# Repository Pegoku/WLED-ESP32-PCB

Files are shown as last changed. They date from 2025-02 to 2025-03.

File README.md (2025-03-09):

# WLED-PCB

This project is a WLED Controller designed using KiCad. The WLED-PCB is controlled using an ESP32 and can be powered via the Screw Terminals. It is capable of driving multiple RGB Strips and Neopixels. It also has a Fuse Holder per channel to protect the circuit from overcurrent.

## Schematic
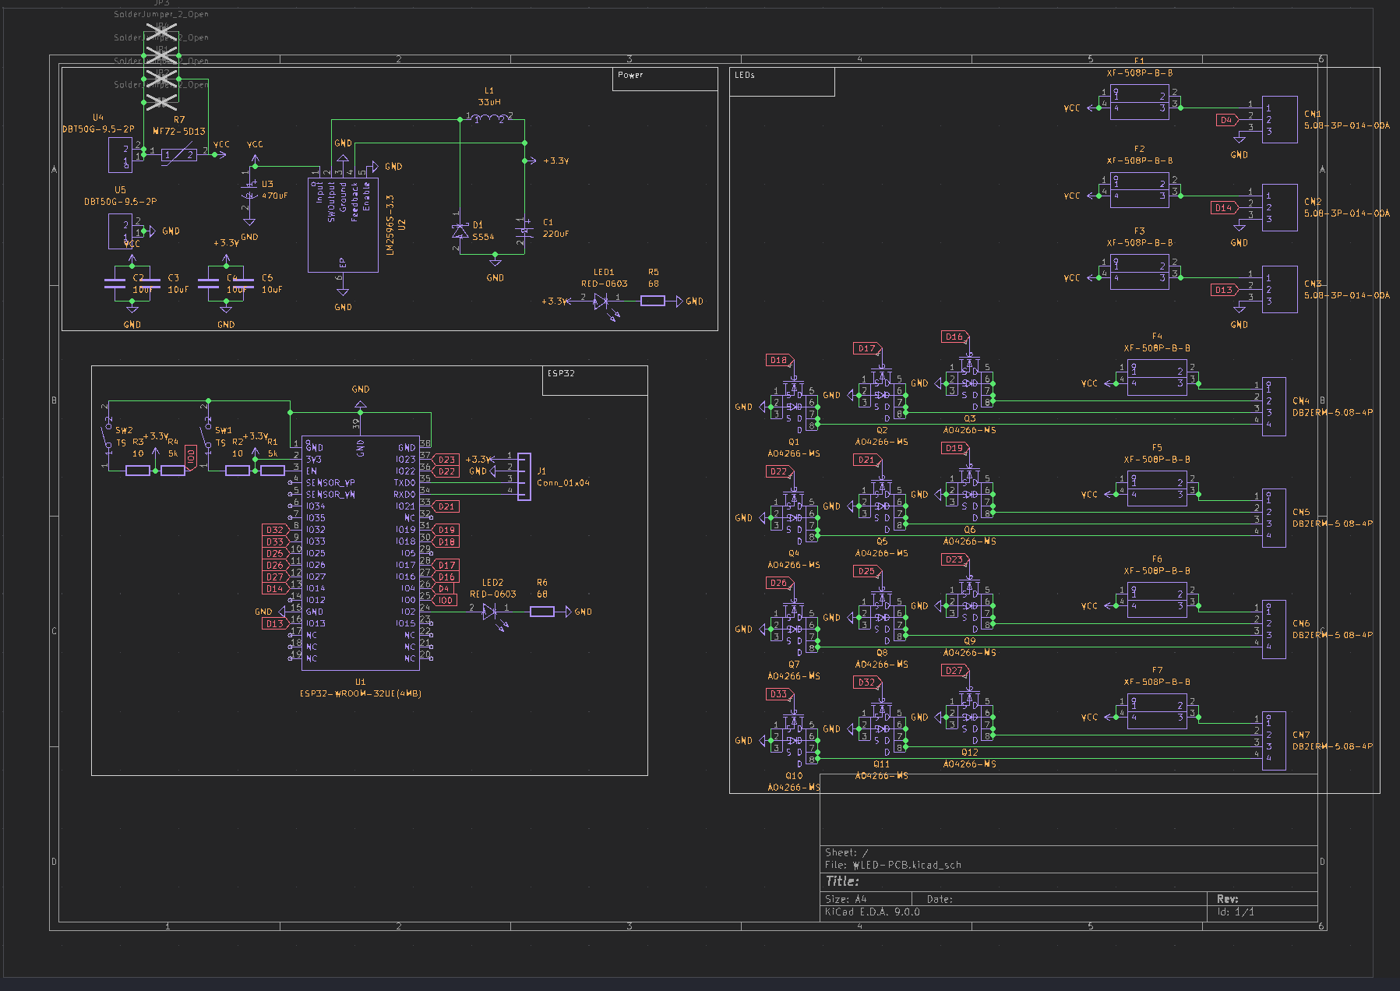
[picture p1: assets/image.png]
Schematic


## PCB Layout
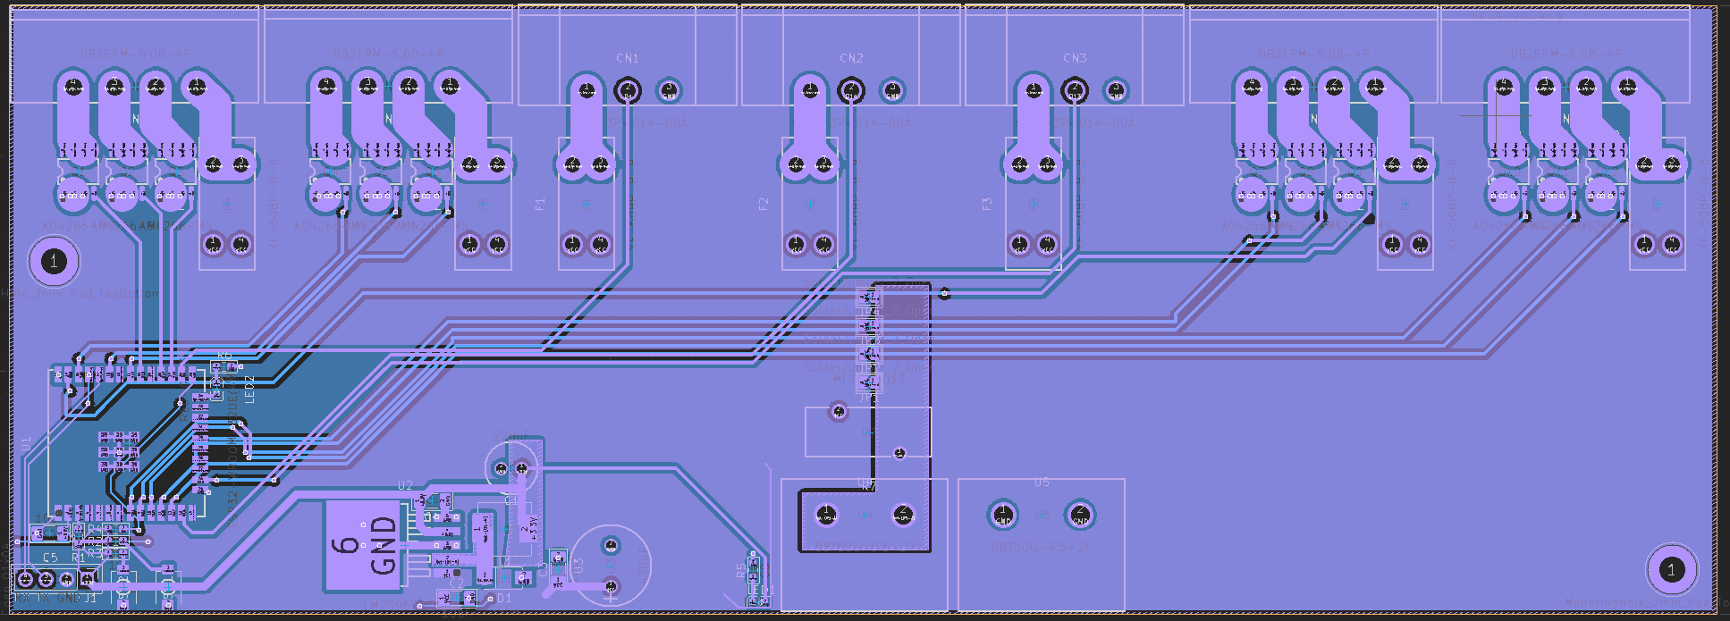
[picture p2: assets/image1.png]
PCB Layout


## 3D View
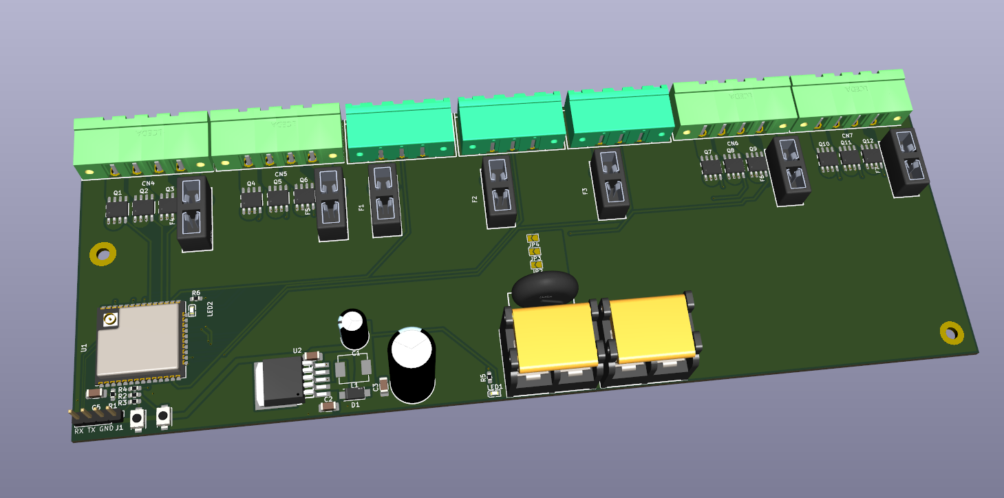
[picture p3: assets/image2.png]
3D View


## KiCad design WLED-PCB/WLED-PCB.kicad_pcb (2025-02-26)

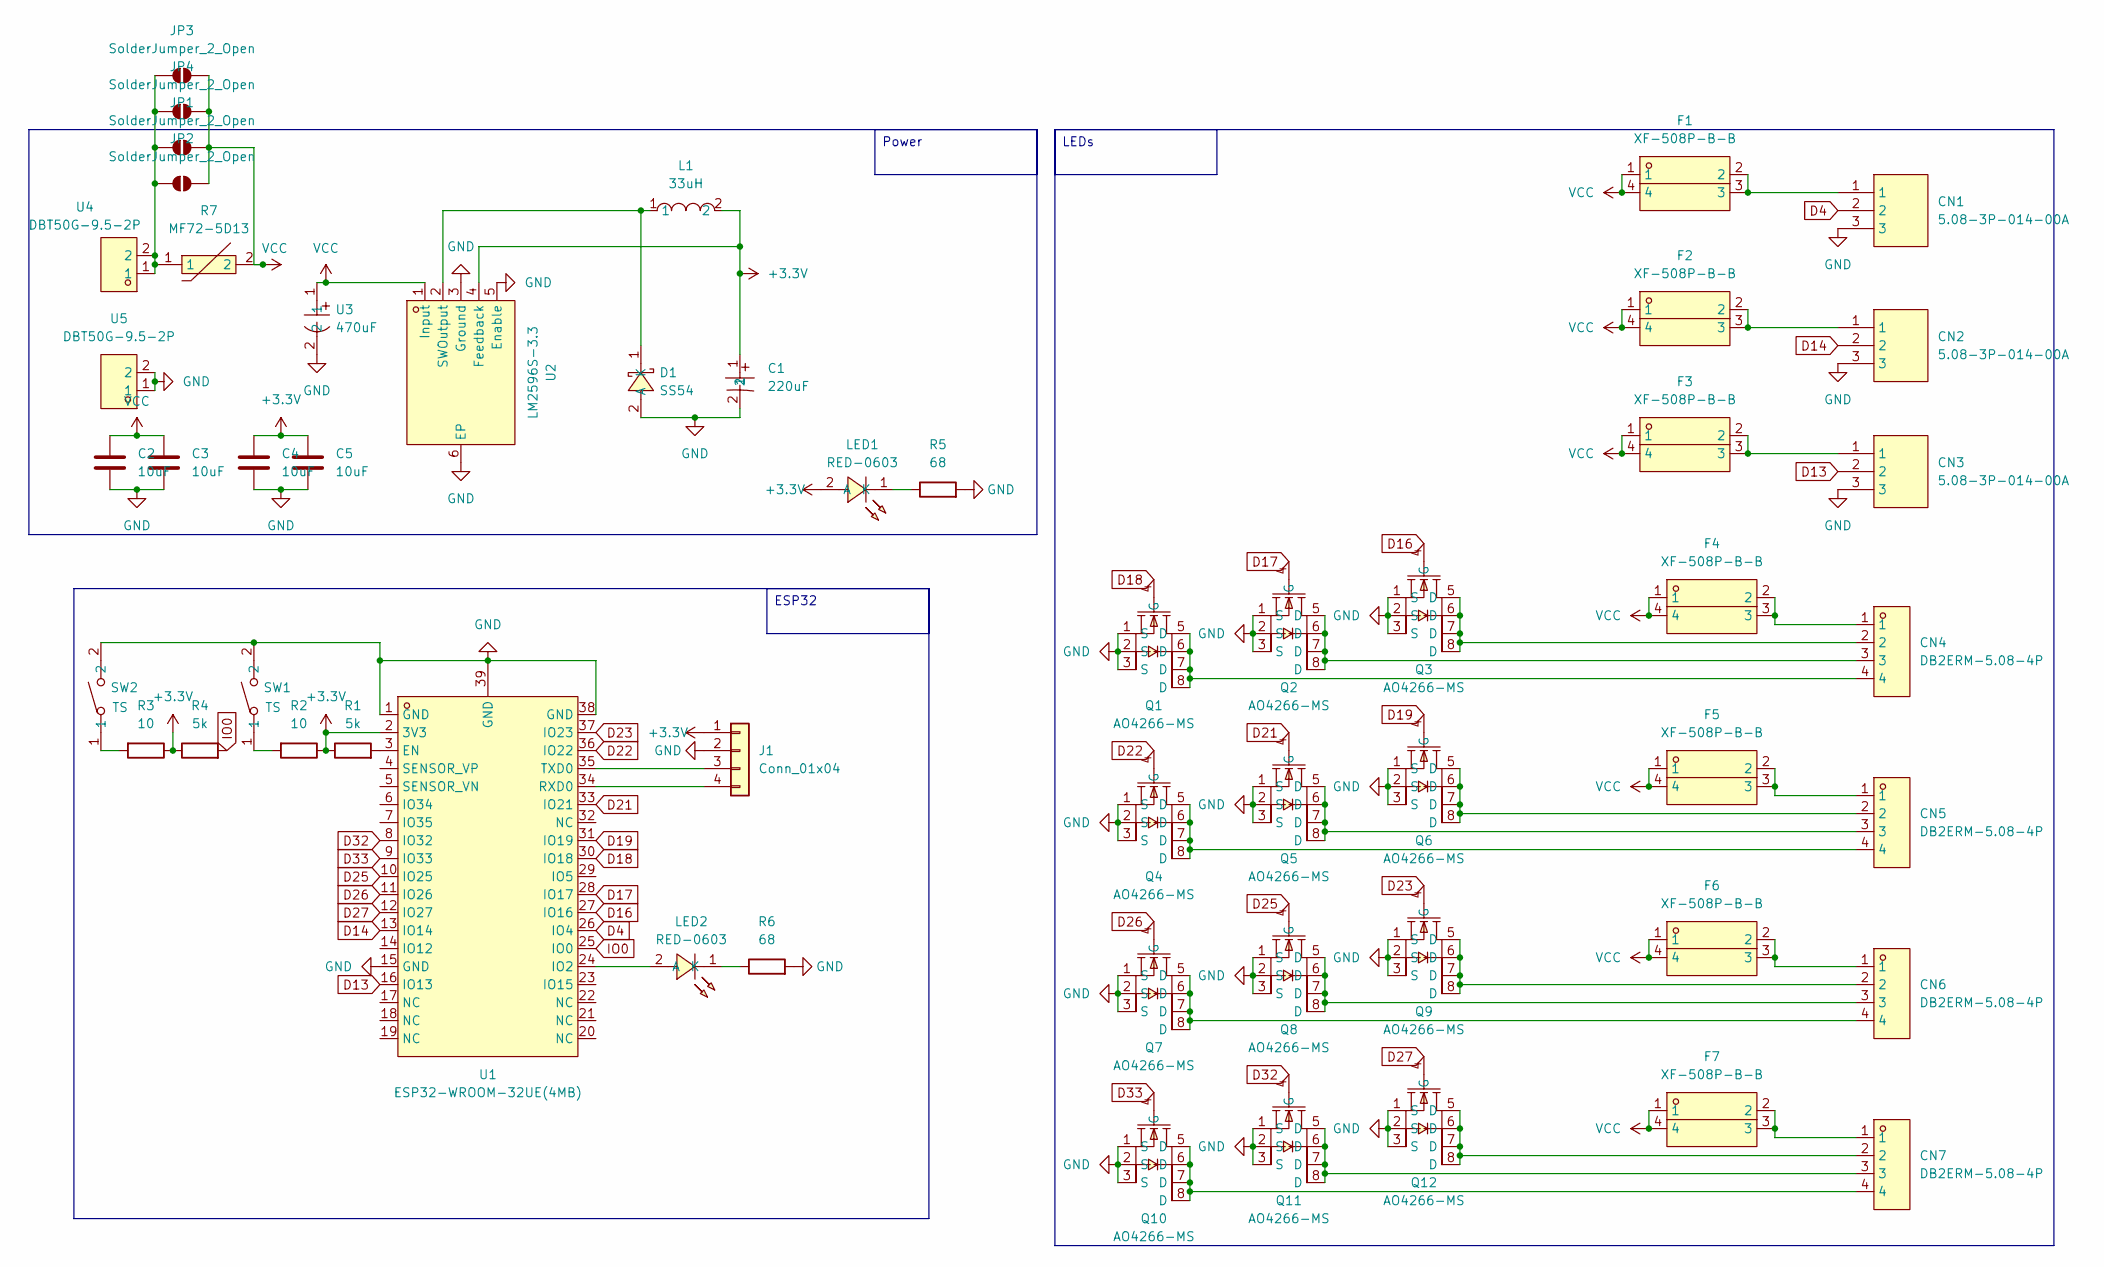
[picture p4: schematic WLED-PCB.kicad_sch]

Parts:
C1: 220uF; CAP-TH_BD6.3-P2.50-D1.0-FD; LCSC Part C122241
C2, C3, C4, C5: 10uF; C_1206_3216Metric_Pad1.33x1.80mm_HandSolder; LCSC C237304
CN1, CN2, CN3: 5.08-3P-014-00A; CONN-TH_WJ2EDGRM-5.08-3P; LCSC Part C49238
CN4, CN5, CN6, CN7: DB2ERM-5.08-4P; CONN-TH_4P-P5.08_DB2ERM-5.08-4P; LCSC Part C395755
D1: SS54; SMA_L4.3-W2.6-LS5.0-RD; LCSC Part C3018536
F1, F2, F3, F4, F5, F6, F7: XF-508P-B-B; FUSE-TH_4P-L16.0-W6.7; LCSC Part C19727305
J1: Conn_01x04; PinHeader_1x04_P2.54mm_Vertical
JP1, JP2, JP3, JP4: SolderJumper_2_Open; SolderJumper-2_P1.3mm_Open_TrianglePad1.0x1.5mm
L1: 33uH; IND-SMD_L7.1-W6.6_SRP6030VA; LCSC Part C22463826
LED1, LED2: RED-0603; LED0603-RD_RED; LCSC Part C965799
Q1, Q2, Q3, Q4, Q5, Q6, Q7, Q8, Q9, Q10, Q11, Q12: AO4266-MS; SOP-8_L4.9-W3.9-P1.27-LS6.0-BL; LCSC Part C3008148
R1, R4: 5k; R_0603_1608Metric_Pad0.98x0.95mm_HandSolder
R2, R3: 10; R_0603_1608Metric_Pad0.98x0.95mm_HandSolder
R5, R6: 68; R_0603_1608Metric_Pad0.98x0.95mm_HandSolder; LCSC C242566
R7: MF72-5D13; RES-TH_L15.5-W6.0-P7.50-D0.8-S5.20; LCSC Part C72683
SW1, SW2: TS; SW-SMD_L3.9-W3.0-P4.45; LCSC Part C720477
U1: ESP32-WROOM-32UE(4MB); WIFI-SMD_ESP32-WROOM-32UE; LCSC Part C701344
U2: LM2596S-3.3; TO-263-5_L10.0-W9.0-P1.70-LS15.2-BR; LCSC Part C7419978
U3: 470uF; CAP-TH_BD10.0-P5.00-D0.6-FD; LCSC Part C5438877
U4, U5: DBT50G-9.5-2P; CONN-TH_2P-P9.50_DBT50G-9.5-2P; LCSC Part C395958

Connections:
+3.3V: C1.1, C4.1, C5.1, J1.1, L1.2, LED1.2 (A), R1.1, R2.1, R3.1, R4.1, U1.2 (3V3), U2.4 (Feedback)
D4: CN1.2, U1.26 (IO4)
D13: CN3.2, U1.16 (IO13)
D14: CN2.2, U1.13 (IO14)
D16: Q3.4 (G), U1.27 (IO16)
D17: Q2.4 (G), U1.28 (IO17)
D18: Q1.4 (G), U1.30 (IO18)
D19: Q6.4 (G), U1.31 (IO19)
D21: Q5.4 (G), U1.33 (IO21)
D22: Q4.4 (G), U1.36 (IO22)
D23: Q9.4 (G), U1.37 (IO23)
D25: Q8.4 (G), U1.10 (IO25)
D26: Q7.4 (G), U1.11 (IO26)
D27: Q12.4 (G), U1.12 (IO27)
D32: Q11.4 (G), U1.8 (IO32)
D33: Q10.4 (G), U1.9 (IO33)
GND: C1.2, C2.2, C3.2, C4.2, C5.2, CN1.3, CN2.3, CN3.3, D1.2 (A), J1.2, Q1.1 (S), Q1.2 (S), Q1.3 (S), Q2.1 (S), Q2.2 (S), Q2.3 (S), Q3.1 (S), Q3.2 (S), Q3.3 (S), Q4.1 (S), Q4.2 (S), Q4.3 (S), Q5.1 (S), Q5.2 (S), Q5.3 (S), Q6.1 (S), Q6.2 (S), Q6.3 (S), Q7.1 (S), Q7.2 (S), Q7.3 (S), Q8.1 (S), Q8.2 (S), Q8.3 (S), Q9.1 (S), Q9.2 (S), Q9.3 (S), Q10.1 (S), Q10.2 (S), Q10.3 (S), Q11.1 (S), Q11.2 (S), Q11.3 (S), Q12.1 (S), Q12.2 (S), Q12.3 (S), R5.2, R6.2, SW1.2, SW2.2, U1.1 (GND), U1.15 (GND), U1.38 (GND), U1.39 (GND), U2.3 (Ground), U2.5 (Enable), U2.6 (EP), U3.2, U5.1, U5.2
IO0: R4.2, U1.25 (IO0)
unnamed: CN1.1, F1.2, F1.3
unnamed: CN2.1, F2.2, F2.3
unnamed: CN3.1, F3.2, F3.3
unnamed: CN4.1, F4.2, F4.3
unnamed: CN4.2, Q3.5 (D), Q3.6 (D), Q3.7 (D), Q3.8 (D)
unnamed: CN4.3, Q2.5 (D), Q2.6 (D), Q2.7 (D), Q2.8 (D)
unnamed: CN4.4, Q1.5 (D), Q1.6 (D), Q1.7 (D), Q1.8 (D)
unnamed: CN5.1, F5.2, F5.3
unnamed: CN5.2, Q6.5 (D), Q6.6 (D), Q6.7 (D), Q6.8 (D)
unnamed: CN5.3, Q5.5 (D), Q5.6 (D), Q5.7 (D), Q5.8 (D)
unnamed: CN5.4, Q4.5 (D), Q4.6 (D), Q4.7 (D), Q4.8 (D)
unnamed: CN6.1, F6.2, F6.3
unnamed: CN6.2, Q9.5 (D), Q9.6 (D), Q9.7 (D), Q9.8 (D)
unnamed: CN6.3, Q8.5 (D), Q8.6 (D), Q8.7 (D), Q8.8 (D)
unnamed: CN6.4, Q7.5 (D), Q7.6 (D), Q7.7 (D), Q7.8 (D)
unnamed: CN7.1, F7.2, F7.3
unnamed: CN7.2, Q12.5 (D), Q12.6 (D), Q12.7 (D), Q12.8 (D)
unnamed: CN7.3, Q11.5 (D), Q11.6 (D), Q11.7 (D), Q11.8 (D)
unnamed: CN7.4, Q10.5 (D), Q10.6 (D), Q10.7 (D), Q10.8 (D)
unnamed: D1.1 (K), L1.1, U2.2 (SWOutput)
unnamed: J1.3, U1.35 (TXD0)
unnamed: J1.4, U1.34 (RXD0)
unnamed: JP1.1 (A), JP2.1 (A), JP3.1 (A), JP4.1 (A), R7.1, U4.1, U4.2
unnamed: LED1.1 (K), R5.1
unnamed: LED2.2 (A), U1.24 (IO2)
unnamed: LED2.1 (K), R6.1
unnamed: R2.2, SW1.1
unnamed: R3.2, SW2.1
unnamed: R1.2, U1.3 (EN)
VCC: C2.1, C3.1, F1.1, F1.4, F2.1, F2.4, F3.1, F3.4, F4.1, F4.4, F5.1, F5.4, F6.1, F6.4, F7.1, F7.4, JP1.2 (B), JP2.2 (B), JP3.2 (B), JP4.2 (B), R7.2, U2.1 (Input), U3.1

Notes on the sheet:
LEDs
ESP32
Power

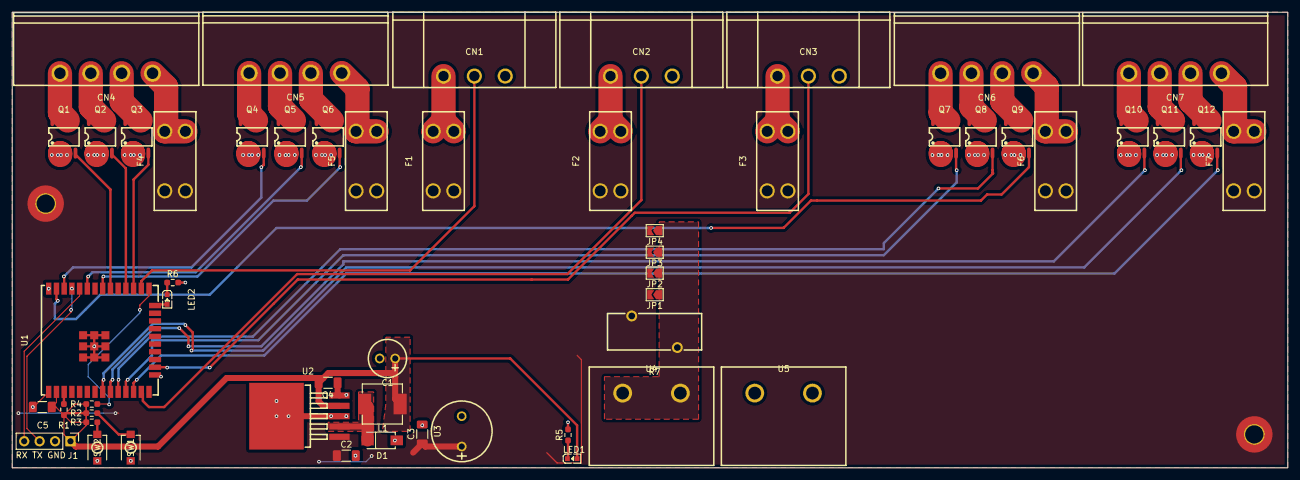
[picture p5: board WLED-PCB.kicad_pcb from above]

Board: 2 copper layers, 210.0 x 75.0 mm, 54 parts (0 on the bottom side), 48 nets.
